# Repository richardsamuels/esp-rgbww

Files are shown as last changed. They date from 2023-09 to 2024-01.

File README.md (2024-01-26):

# esp32-rgbww
This is a custom ESP32-based LED controller that easily links with
ESPhome and Home Assistant.

The device has 5 low-side MOSFETs for controlling LEDs up to 24V. Terminal block
rated for 8A of current, barrel jack rated for 6A. Device must be flashed
using a Tag-Connect TC2030-USB-NL cable. Two config files are available.

## PCB and Pinout
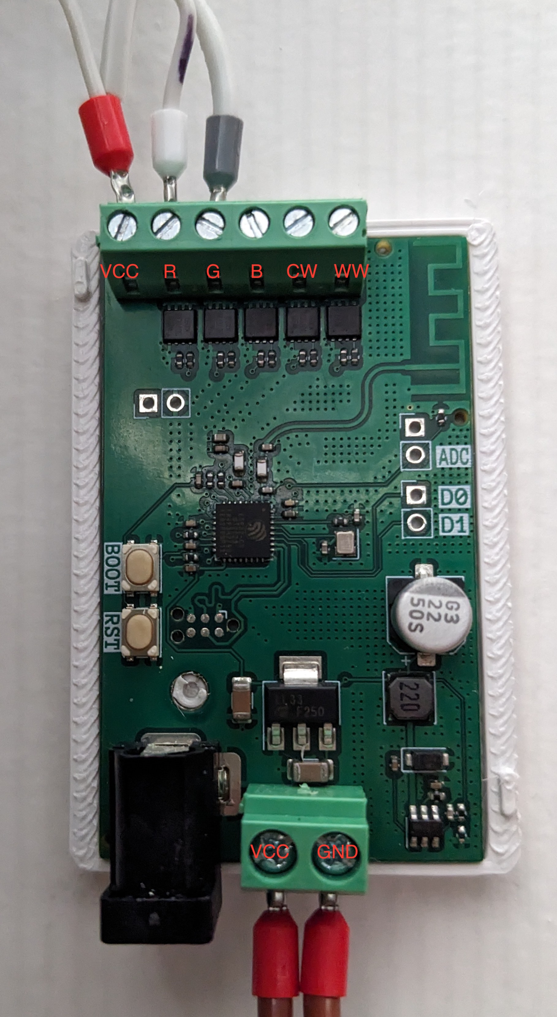
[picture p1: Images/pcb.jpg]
PCB


### GPIO Pin Index

| Labeled Pin | GPIO Pin |
| --- | --- |
| R | 10 |
| G | 7 |
| B | 6 |
| CW | 5 |
| WW | 3 |
| D0 | 28 |
| D1 | 27 |
| ADC | 4 |

## 3D Printed Case

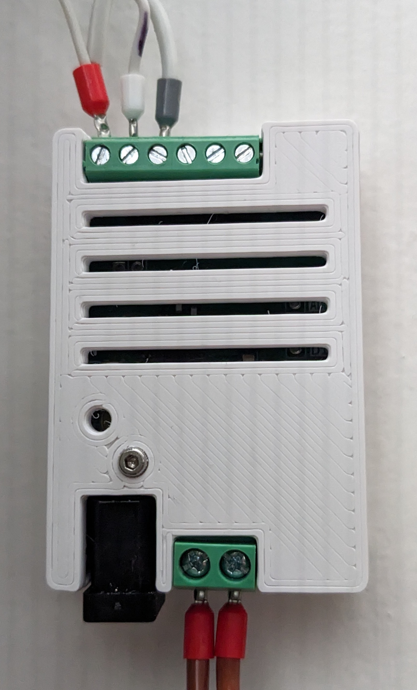
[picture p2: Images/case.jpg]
case


3D Printable parts are available in the STL directory. These parts should be
printed from a plastic capable of withstanding 70C internal temperatures (ABS
recommended). An M2 bolt can be used to secure the case together, however care
should be used as the female end is vulnerable to cracking.

## Configuration

### 2channel-monochrome.yaml
Provides 2 independent channels of monochrome LED support (trivially extendable
to 5).

### rgbww.yaml
Provides 5 channels of LED support, intended for 6 wire LED strips (RGB, CW,
WW).

Exposed to ESPhome/Home Assistant as a RGBWW light with color interlock
enabled.

## Future Work
1. The case's screw hole can crack if over-torqued, or if the print is of low
quality. A future revision should allow for a larger female end to avoid cracks
and layer separation while screwing the case halves together.
2. The PWM frequency can cause visible artifacts on rolling shutter cameras. 
Experiment with the PWM frequency and capacitors to reduce these artifacts
3. Due to gate capacitance, the LEDs can take up two seconds to respond to
"turn off" signals. Use a proper gate driver circuit for the MOSFETs

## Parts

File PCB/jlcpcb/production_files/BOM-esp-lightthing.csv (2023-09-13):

Comment | Designator | Footprint | LCSC
AOZ1282CI | U201 | SOT-23-6 | C111916
WSD3070DN | Q201,Q202,Q203,Q204,Q205 | WSD3070DN | C148387
10n | C306 | C_0402_1005Metric | C15195
12p | C312,C313 | C_0402_1005Metric | C1547
10u | C307 | C_0402_1005Metric | C15525
0402CG200J500NT | C203 | C_0402_1005Metric | C1554
3p3 | C301,C302 | C_0402_1005Metric | C1565
FNR4012S220MT | L201 | L_Changjiang_FNR4012S | C167789
0 | R303 | R_0402_1005Metric | C17168
RM04FTN9531 | R202 | R_0402_1005Metric | C173840
VES220M1HTR-0605 | C204 | CP_Elec_6.3x5.3 | C176676
100R | R203,R205,R207,R209,R211,R213 | R_0402_1005Metric | C25076
Crystal_GND24 | Y1 | Crystal_SMD_2016-4Pin_2.0x1.6mm | C255898
100k | R204,R206,R208,R210,R212 | R_0402_1005Metric | C25741
0402WGF4992TCE | R201 | R_0402_1005Metric | C25897
5k1 | R301,R302,R304,R305 | R_0402_1005Metric | C25905
2n2 | L301,L302 | L_0603_1608Metric | C29682
CL05B104KB54PNC | C201,C202,C303,C304,C308,C309,C310,C311 | C_0402_1005Metric | C307331
LDL111733R | U202 | SOT-223-3_TabPin2 | C435835
SW_Push | SW301,SW302 | SW_SPST_PTS810 | C470426
ESP32-C3FN4 | U1 | QFN-32-1EP_5x5mm_P0.5mm_EP3.45x3.45mm | C5143572
1u | C305 | C_0402_1005Metric | C52923
12V 7.5A | J201 | DC-005H-D025 | C5353839
22uF | C205,C206 | C_1206_3216Metric | C5672
DSS14 | D201 | D_SOD-123F | C59293
Conn_01x06_Socket | J101 | WJ124-3.81-6P | C69810
12-24V | J202 | WJ126V-5.0-2P | C8404
USB_TC2030-USB-NL | J203 | Tag-Connect_TC2030-IDC-NL_2x03_P1.27mm_Vertical
2.4GHz aerial | AE301 | Texas_SWRA117D_2.4GHz_Left
5k1 | R101 | R_0402_1005Metric
Conn_01x02_Pin | J103 | PinHeader_1x02_P2.54mm_Vertical
Conn_01x02_Pin | J102 | PinHeader_1x02_P2.54mm_Vertical
DNP | C101 | PinHeader_1x02_P2.54mm_Vertical

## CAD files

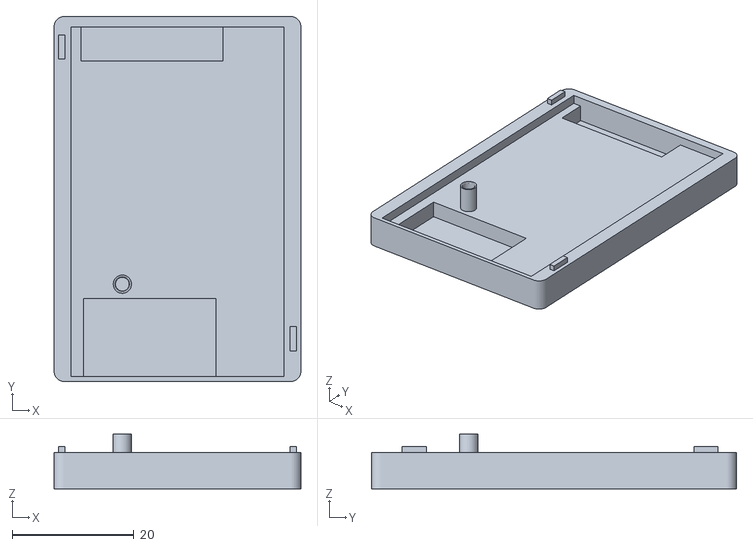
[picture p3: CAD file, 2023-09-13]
STL/base.stl
40.5 x 59.9 x 9.00

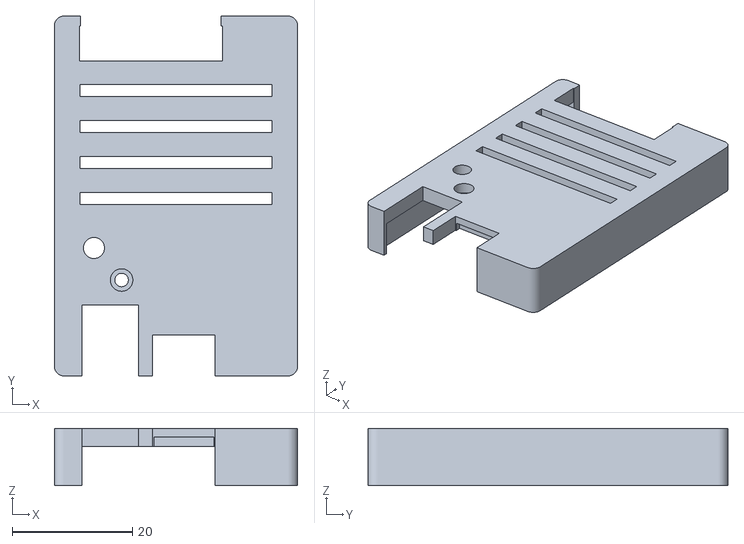
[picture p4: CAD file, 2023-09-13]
STL/cover.stl
40.5 x 59.9 x 9.50

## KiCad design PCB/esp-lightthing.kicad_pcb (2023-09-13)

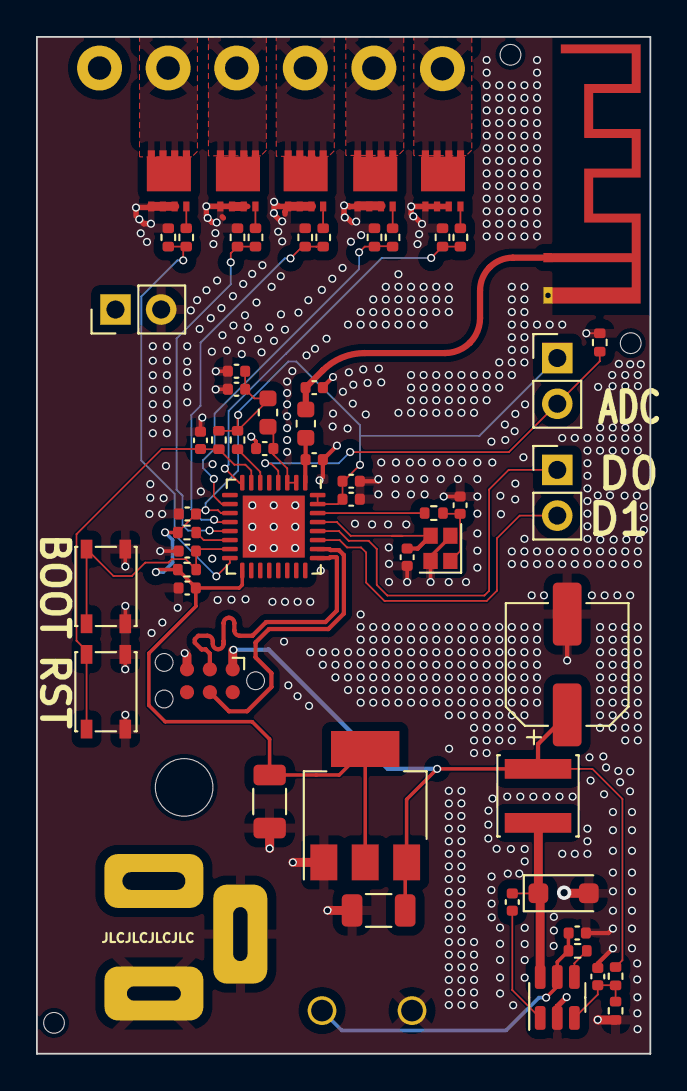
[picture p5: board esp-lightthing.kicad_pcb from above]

Board: 4 copper layers, 34.1 x 56.5 mm, 61 parts (0 on the bottom side), 38 nets.

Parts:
AE301: 2.4GHz aerial; Texas_SWRA117D_2.4GHz_Left
C101: DNP; PinHeader_1x02_P2.54mm_Vertical
C201, C202: CL05B104KB54PNC; C_0402_1005Metric
C203: 0402CG200J500NT; C_0402_1005Metric
C204: VES220M1HTR-0605; CP_Elec_6.3x5.3
C205, C206: 22uF; C_1206_3216Metric
C301, C302: 3p3; C_0402_1005Metric
C303, C304: 100n; C_0402_1005Metric
C305: 1u; C_0402_1005Metric
C306: 10n; C_0402_1005Metric
C307: 10u; C_0402_1005Metric
C308, C309, C310, C311: 0.1u; C_0402_1005Metric
C312, C313: 12p; C_0402_1005Metric
D201: DSS14; D_SOD-123F
J101: Conn_01x06_Socket; WJ124-3.81-6P
J102, J103: Conn_01x02_Pin; PinHeader_1x02_P2.54mm_Vertical
J201: 12V 7.5A; DC-005H-D025
J202: 12-24V; WJ126V-5.0-2P
J203: USB_TC2030-USB-NL; Tag-Connect_TC2030-IDC-NL_2x03_P1.27mm_Vertical
L201: FNR4012S220MT; L_Changjiang_FNR4012S
L301, L302: 2n2; L_0603_1608Metric
Q201, Q202, Q203, Q204, Q205: WSD3070DN
R101, R301, R302, R304, R305: 5k1; R_0402_1005Metric
R201: 0402WGF4992TCE; R_0402_1005Metric
R202: RM04FTN9531; R_0402_1005Metric
R203, R205, R207, R209, R211, R213: 100R; R_0402_1005Metric
R204, R206, R208, R210, R212: 100k; R_0402_1005Metric
R303: 0; R_0402_1005Metric
SW301, SW302: SW_Push; SW_SPST_PTS810
U1: ESP32-C3FN4; QFN-32-1EP_5x5mm_P0.5mm_EP3.45x3.45mm
U201: AOZ1282CI; SOT-23-6
U202: LDL111733R; SOT-223-3_TabPin2
Y1: Crystal_GND24; Crystal_SMD_2016-4Pin_2.0x1.6mm

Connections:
+3V3: C206.1, C305.1, C306.1, C307.1, C308.1, C310.1, C311.1, J102.1, L302.1, R301.1, R302.1, R304.2, R305.2, U1.11 (VDD3P3_RTC), U1.17 (VDD3P3_CPU), U1.31 (VDDA), U1.32 (VDDA), U202.2 (VO)
+5V: C204.1, C205.1, J203.1 (VBUS), L201.2, R201.2, U202.3 (VI)
/ADC: J102.2, R101.1, U1.4 (XTAL_32K_P/ADC1_CH0)
/D0: J103.1, U1.28 (U0TXD/GPIO21)
/D1: J103.2, U1.27 (U0RXD/GPIO20)
/ESP32/BOOT: C304.1, R302.2, SW302.2, U1.15 (GPIO9/BOOT)
/ESP32/D+: J203.4 (D+), U1.26 (GPIO19/USB_D+)
/ESP32/D-: J203.3 (D-), U1.25 (GPIO18/USB_D-)
/ESP32/GATE_B: R207.1, R208.1, U1.12 (MTCK/GPIO6)
/ESP32/GATE_CW: R209.1, R210.1, U1.10 (MTDI/GPIO5/ADC2_CH0)
/ESP32/GATE_G: R205.1, R206.1, U1.13 (MTDO/GPIO7)
/ESP32/GATE_R: R203.1, R204.1, U1.16 (GPIO10)
/ESP32/GATE_WW: R211.1, R212.1, U1.8 (GPIO3/ADC1_CH3)
/ESP32/LNA: C302.1, L301.2, U1.1 (LNA_IN)
/ESP32/LNA_Z=50: AE301.1 (FEED), C301.1, L301.1
/ESP32/RESET: C303.1, R301.2, SW301.2, U1.7 (CHIP_EN)
/ESP32/VDD3P3: C309.1, L302.2, U1.2 (VDD3P3), U1.3 (VDD3P3)
/ESP32/XTAL_N: C313.1, U1.29 (XTAL_N), Y1.3
/ESP32/XTAL_P: R303.1, U1.30 (XTAL_P)
/power/B: J101.4, Q203.3 (D)
/power/CW: J101.5, Q204.3 (D)
/power/G: J101.3, Q202.3 (D)
/power/LX_5V: C202.1, D201.1 (K), L201.1, U201.6 (LX)
/power/R: J101.2, Q201.3 (D)
/power/WW: J101.6, Q205.3 (D)
GND: AE301.2 (PCB_Trace), C101.2, C201.2, C203.2, C204.2, C205.2, C206.2, C301.2, C302.2, C303.2, C304.2, C305.2, C306.2, C307.2, C308.2, C309.2, C310.2, C311.2, C312.2, C313.2, D201.2 (A), J201.2, J202.2, J203.5 (GND), Q201.1 (S), Q202.1 (S), Q203.1 (S), Q204.1 (S), Q205.1 (S), R101.2, R202.2, R204.2, R206.2, R208.2, R210.2, R212.2, SW301.1, SW302.1, U1.33 (GND), U201.2 (GND), U202.1 (GND), Y1.2, Y1.4
unnamed: C312.1, R303.2, Y1.1
unnamed: Q201.2 (G), R203.2
unnamed: Q202.2 (G), R205.2
unnamed: Q203.2 (G), R207.2
unnamed: Q204.2 (G), R209.2
unnamed: Q205.2 (G), R211.2
unnamed: R304.1, U1.6 (GPIO2/ADC1_CH2)
unnamed: R305.1, U1.14 (GPIO8)
unnamed: C202.2, U201.1 (BST)
unnamed: R213.1, U201.4 (EN)
unnamed: C203.1, R201.1, R202.1, U201.3 (FB)
VCC: C101.1, C201.1, J101.1, J201.1, J202.1, R213.2, U201.5 (VIN)

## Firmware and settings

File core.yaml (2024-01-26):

substitutions:
  name: "name"

esphome:
  name: "${name}"
  platformio_options:
    board_build.flash_mode: dio
    board_build.f_flash: 40000000L
    board_build.flash_size: 4MB
  on_boot:
    - priority: 500
      then:
        - esp32_ble_tracker.stop_scan:
    - priority: 100
      then:
        - delay: 10s
        - esp32_ble_tracker.start_scan:
            continuous: true

esp32:
  board: esp32-c3-devkitm-1
  variant: esp32c3
  framework:
    #type: arduino
    type: esp-idf

# Enable logging
logger:
  logs:
    esp-idf: ERROR

<<: !include secrets.yaml

esp32_ble_tracker:
  scan_parameters:
    active: true
    continuous: true

bluetooth_proxy:
  active: true

output:
  - platform: ledc
    id: output_r
    pin: GPIO10
    max_power: 80%
    min_power: 1%
    zero_means_zero: true
  - platform: ledc
    id: output_g
    pin: GPIO7
    max_power: 80%
    min_power: 1%
    zero_means_zero: true
  - platform: ledc
    id: output_b
    pin: GPIO6
    max_power: 80%
    min_power: 1%
    zero_means_zero: true
  - platform: ledc
    id: output_cw
    pin: GPIO5
    max_power: 80%
    min_power: 1%
    zero_means_zero: true
  - platform: ledc
    id: output_ww
    pin: GPIO3
    max_power: 80%
    min_power: 1%
    zero_means_zero: true

sensor:
  - platform: internal_temperature
    name: "ESP32 Die Temp"
